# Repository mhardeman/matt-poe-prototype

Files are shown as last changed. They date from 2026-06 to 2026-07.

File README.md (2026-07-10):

# matt-poe-prototype
This is a KiCad design containing a schematic & PCB layout for a prototype PoE (Power over Ethernet) PD (Powered Device).

It provides for output isolation between the PoE delivery and the output power rails.  It provides for both 12V and 5V output rails, with a common ground for those two rails.

This is a prototype.  I'm happy to accept issues with questions or suggestions for improvement, and would very happily review any pull requests that come in.

## Update 2026/07/09
Apparently some one(s) at [PCBWay](https://pcbway.com) saw this Github project or my post(s) about it on Reddit, because a representative from PCBWay reached out to me and offered to sponsor a run of these boards for free and even let me get a free solder stencil with the boards, all for the simple ask that I provide an honest review of the sponsored boards & stencil.  My review is: they look & feel great, and they function fantastically.  I'll be posting more -- including an assembly and testing video -- in the coming days.  In the mean time, check out the [photos of the PCBWay boards](pcbway/)  All told, PCBWay let me put together a purchase of these boards, the stencil, and some premium options, and shipping, all without cost to me.  It's wonderful to see a company serving both hobbyists and industry ALSO materially contribute!  I'm grateful.

## Detailed Description

This design utilizes the 3Peak TPE15017 and/or Monolithic Power Systems MP8017 -- they're largely interchangeable in this design, though tolerances on the 3Peak seem to be favorable, which can improve your efficiency.  This tiny IC handles the PoE power detection and classification and provides an active-clamp flyback controller with integrated low-side & clamp MOSFETs.  This part, in conjunction with an appropriate transformer provides a 12V output rail, which is further routed in this design to an inexpensive buck converter to provide for a 5V output rail.

In my testing up to this point, this design easily provides at least 10W of usable power out the 5V rail.  I've had it pulling 5V/2A on my DC test load continuously for several days.

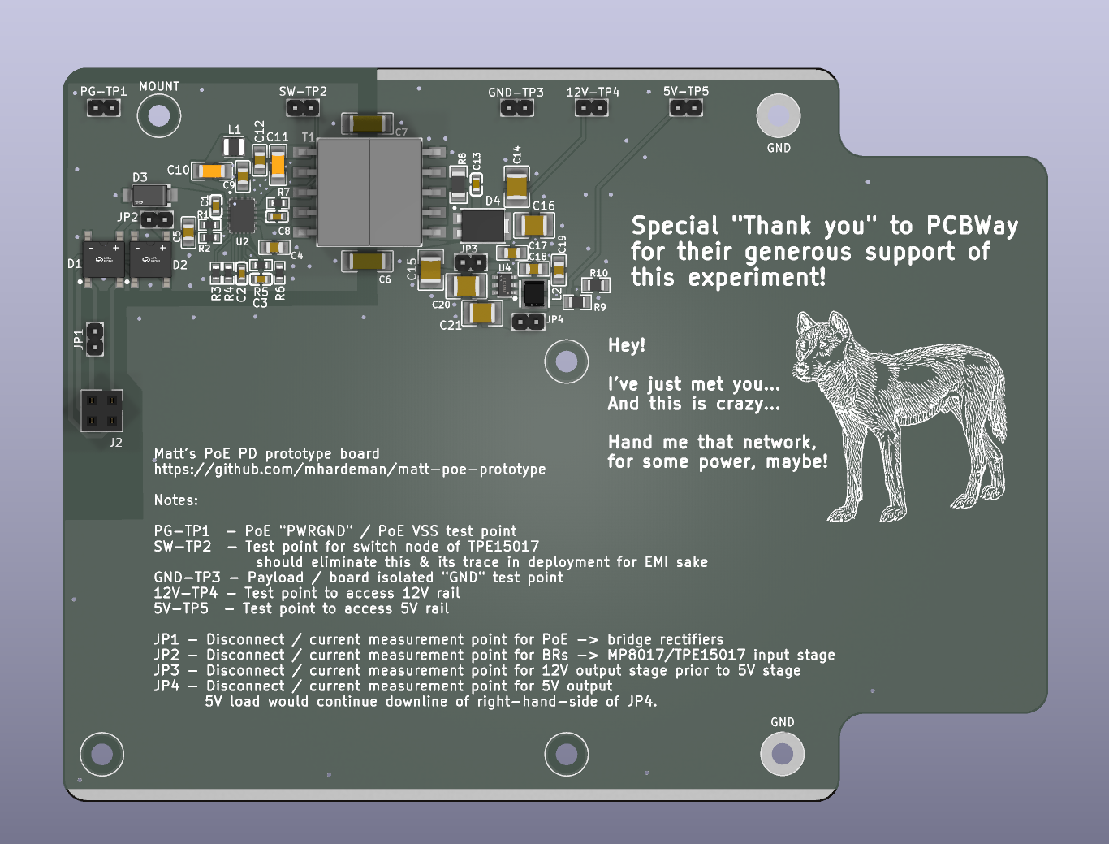
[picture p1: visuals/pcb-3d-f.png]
3D view


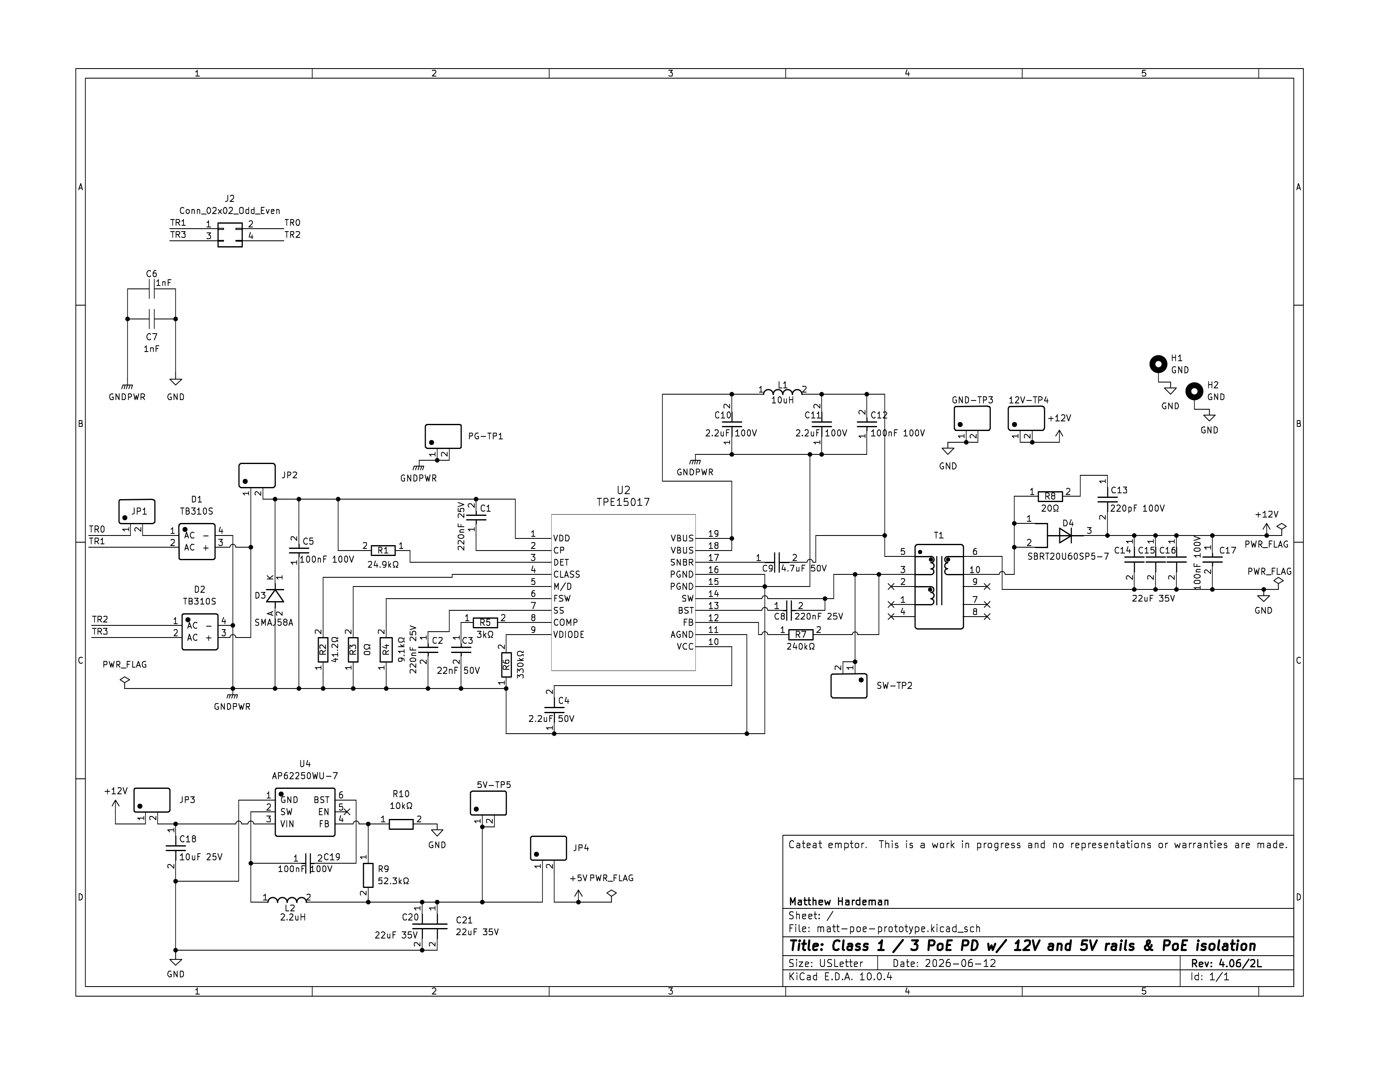
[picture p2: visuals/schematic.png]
Schematic


[Bill of Materials](matt-poe-prototype.csv)

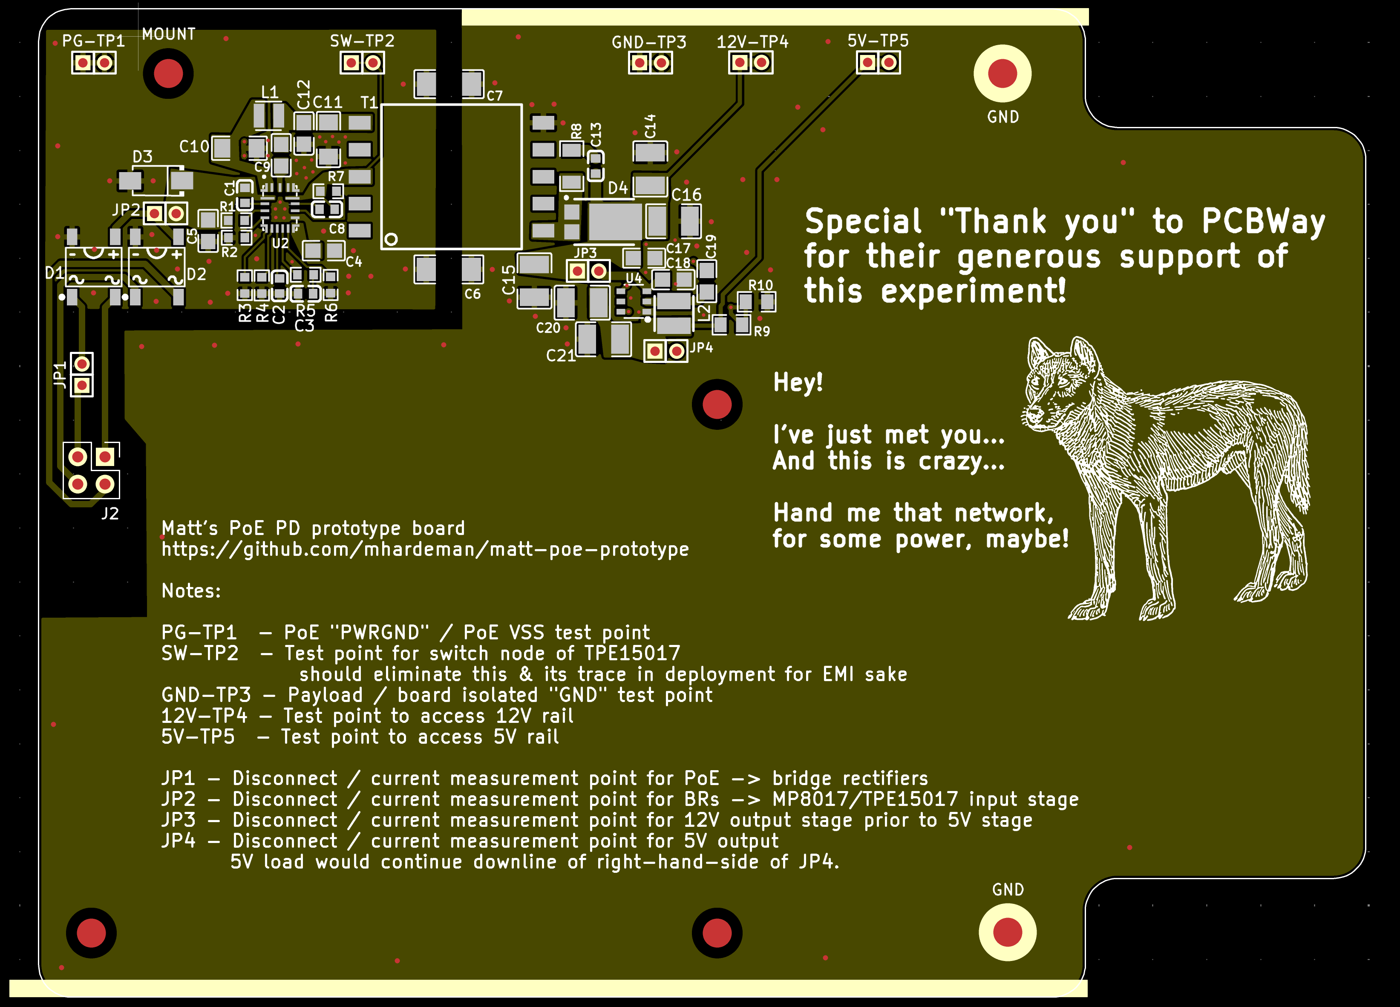
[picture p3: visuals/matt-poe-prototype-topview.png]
Top view


[More visuals](visuals/)

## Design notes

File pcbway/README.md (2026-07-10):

# PCBWay Boards & Stencil
[PCBWay](https://pcbway.com) generously sponsored a run of PCBs and even allowed me to select some premium options, such as 2 ounce copper layers.
Here are a couple of photos of the excellent PCBWay products I received free of charge and a photo of one of the boards as fully assembled by me (Matt).

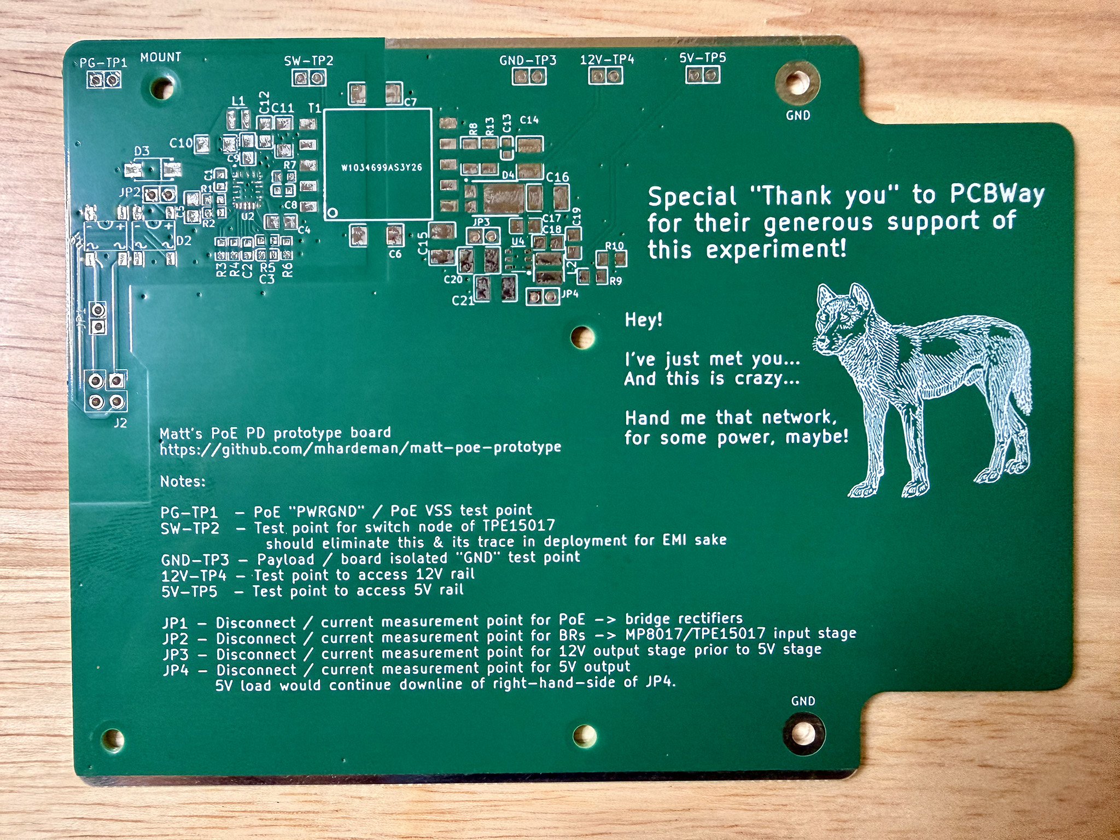
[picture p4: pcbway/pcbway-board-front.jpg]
Photo of front of PCBWay PCB


Take note of the excellent silkscreen -- I didn't put that dingo sketch on there for no reason.  All the fine detail from the design was preserved and faithfully reproduced.  The soldermask feels even more silky-smooth than it looks, while remaining durable and scratch resistant.  The simple HASL surface treatment that I selected was remarkably flat and smooth for HASL.  As you can see below, it supported paste reflow & hand soldering well.

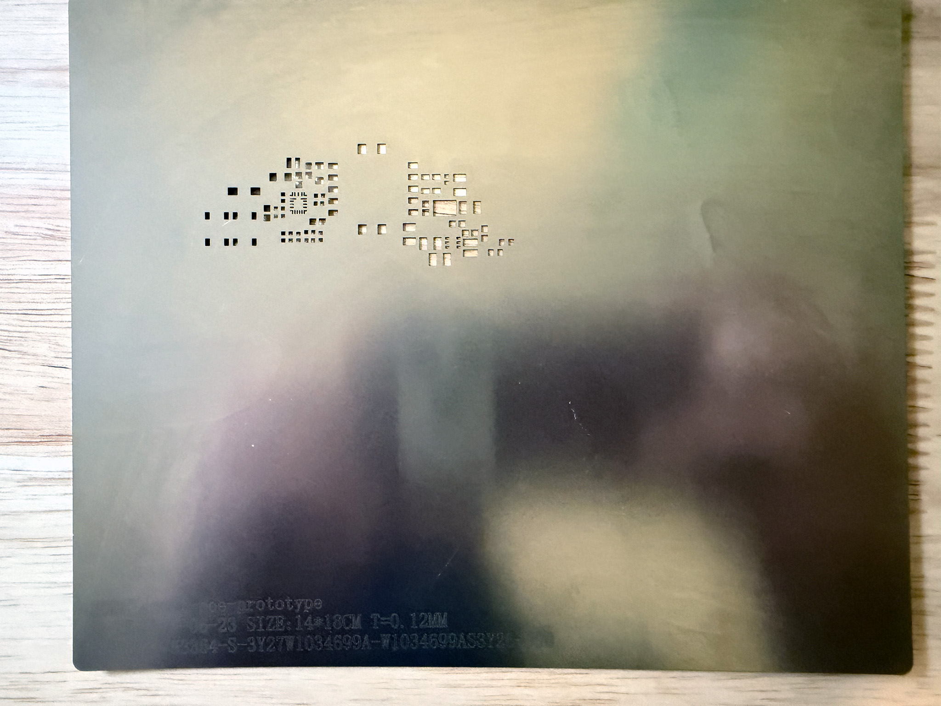
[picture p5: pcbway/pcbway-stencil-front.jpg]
Photo of PCBWay Steel Solder Paste Stencil


I asked PCBWay's representative if I could also get a solder paste stencil to show how easy populating a board with the benefit of one of their stencils can be.  I'll be posting a video of that, but for now look at the fine details and smooth, flawless opening cuts in this nicely electropolished steel stencil.  Functionally, the stencil performed very well; solder paste release was clean and even.

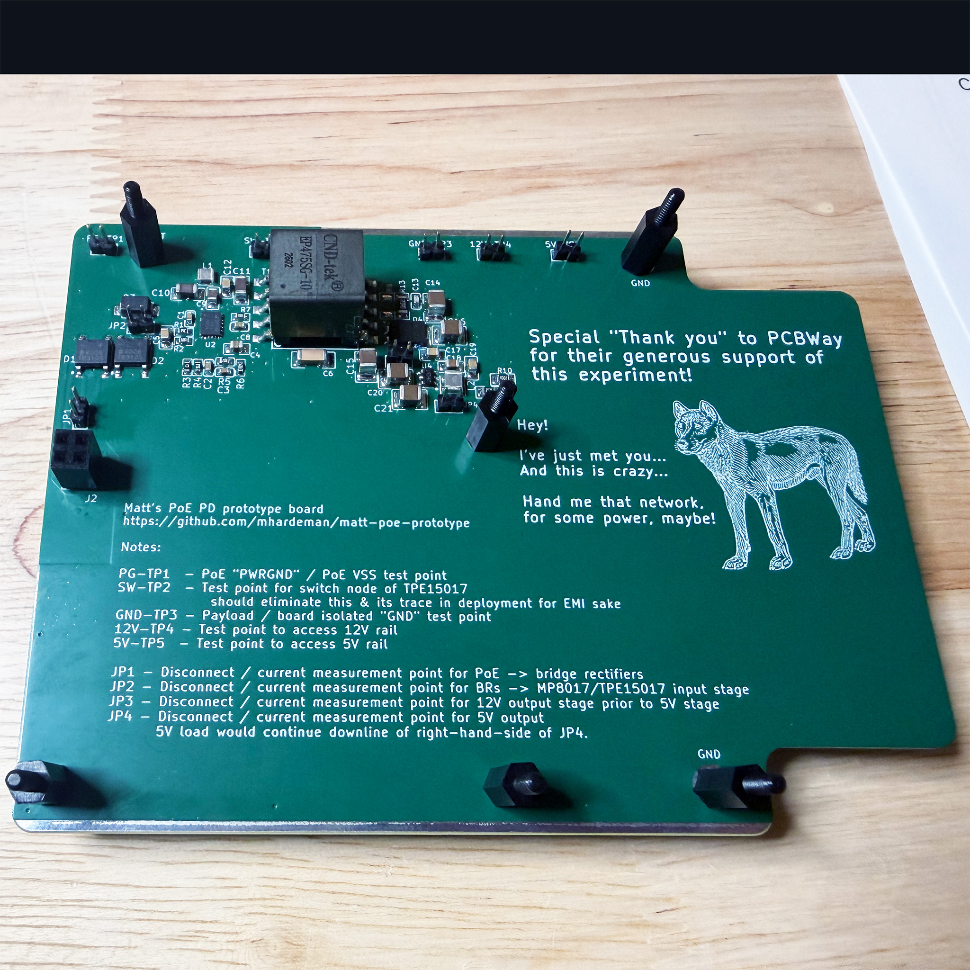
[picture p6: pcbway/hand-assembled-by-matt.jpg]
Photo of their board that I hand populated


I'll ultimately be posting a video of the assembly process, particularly demonstrating how the solder paste stencil can be such a benefit when working with fine-pitch components such as some of those in this design.  In the meantime, here's a photo of the finished board, hand populated.  I wish to emphasize that this assembly was my own work, and not from the assembly service at PCBWay.  Any flaws in the placement or soldering are my own.

# Thanks
I once again wish to express my gratitude to PCBWay for sponsoring a run of boards for this PoE powered device prototype.  The boards they provided are perfectly faithful in form, 
look great, feel premium, and function very well.  It's fantastic to see that a major vendor to both hobbyists and industry is actively seeking out opportunities to collaborate
with people who are building in public!

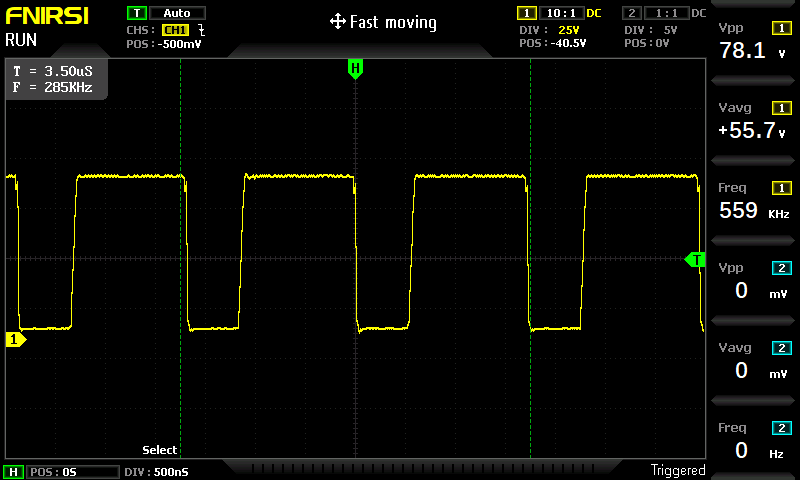
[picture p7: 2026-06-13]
visuals/switching-20260612-3.png

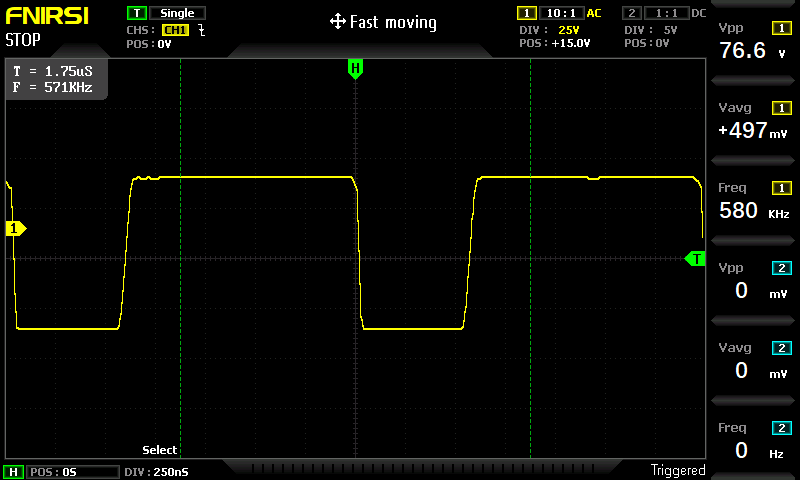
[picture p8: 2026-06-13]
visuals/switching-20260612-2.png

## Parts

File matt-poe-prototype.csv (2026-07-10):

Reference | Value | Manufacturer Part | Manufacturer | LCSC | Description
5V-TP5 | PZ200V-11-02P | PZ200V-11-02P | XFCN | C541856 | -40℃~+105℃ 1 1.5A 1x2P 2.8mm 250V 2P 2mm 2mm 3.9mm Black Brass Pin Header Through Hole 插件,P=2mm Pin Headers ROHS
12V-TP4 | PZ200V-11-02P | PZ200V-11-02P | XFCN | C541856 | -40℃~+105℃ 1 1.5A 1x2P 2.8mm 250V 2P 2mm 2mm 3.9mm Black Brass Pin Header Through Hole 插件,P=2mm Pin Headers ROHS
C1 | 220nF 25V | CL10B224KA8NNNC | Samsung Electro-Mechanics | C21120 | 220nF 25V X7R ±10% 0603 Multilayer Ceramic Capacitors MLCC - SMD/SMT ROHS
C2 | 220nF 25V | CL10B224KA8NNNC | Samsung Electro-Mechanics | C21120 | 220nF 25V X7R ±10% 0603 Multilayer Ceramic Capacitors MLCC - SMD/SMT ROHS
C3 | 22nF 50V | CL10B223KB8NNNC | Samsung Electro-Mechanics | C21122 | 22nF 50V X7R ±10% 0603 Multilayer Ceramic Capacitors MLCC - SMD/SMT ROHS
C4 | 2.2uF 50V | CL21A225KBQNNNE | Samsung Electro-Mechanics | C377773 | 2.2uF 50V X5R ±10% 0805 Multilayer Ceramic Capacitors MLCC - SMD/SMT ROHS
C5 | 100nF 100V | CL21B104KCFNNNE | Samsung Electro-Mechanics | C28233 | 100V 100nF X7R ±10% 0805 Multilayer Ceramic Capacitors MLCC - SMD/SMT ROHS
C6 | 1nF | GR442QR73D102KW01L | Murata Electronics | C76916 | 1nF 2kV X7R ±10% 1808
C7 | 1nF | GR442QR73D102KW01L | Murata Electronics | C76916 | 1nF 2kV X7R ±10% 1808
C8 | 220nF 25V | CL10B224KA8NNNC | Samsung Electro-Mechanics | C21120 | 220nF 25V X7R ±10% 0603 Multilayer Ceramic Capacitors MLCC - SMD/SMT ROHS
C9 | 4.7uF 50V | GRM21BZ71H475KE15L | Murata Electronics | C437557 | 4.7uF 50V X7R ±10% 0805 Multilayer Ceramic Capacitors MLCC - SMD/SMT ROHS
C10 | 2.2uF 100V | CL31B225KCHSNNE | Samsung Electro-Mechanics | C170101 | 100V 2.2uF X7R ±10% 1206 Multilayer Ceramic Capacitors MLCC - SMD/SMT ROHS
C11 | 2.2uF 100V | CL31B225KCHSNNE | Samsung Electro-Mechanics | C170101 | 100V 2.2uF X7R ±10% 1206 Multilayer Ceramic Capacitors MLCC - SMD/SMT ROHS
C12 | 100nF 100V | CL21B104KCFNNNE | Samsung Electro-Mechanics | C28233 | 100V 100nF X7R ±10% 0805 Multilayer Ceramic Capacitors MLCC - SMD/SMT ROHS
C13 | 220pF 100V | GCM1885C2A221JA16D | Murata Electronics | C388907 | 100V 220pF C0G ±5% 0603 Multilayer Ceramic Capacitors MLCC - SMD/SMT ROHS
C14 | 22uF 35V | GMK325BJ226MM-P | Taiyo Yuden | C778721 | 22uF 35V X5R ±20% 1210 Multilayer Ceramic Capacitors MLCC - SMD/SMT ROHS
C15 | 22uF 35V | GMK325BJ226MM-P | Taiyo Yuden | C778721 | 22uF 35V X5R ±20% 1210 Multilayer Ceramic Capacitors MLCC - SMD/SMT ROHS
C16 | 22uF 35V | GMK325BJ226MM-P | Taiyo Yuden | C778721 | 22uF 35V X5R ±20% 1210 Multilayer Ceramic Capacitors MLCC - SMD/SMT ROHS
C17 | 100nF 100V | CL21B104KCFNNNE | Samsung Electro-Mechanics | C28233 | 100V 100nF X7R ±10% 0805 Multilayer Ceramic Capacitors MLCC - SMD/SMT ROHS
C18 | 10uF 25V | GRM21BZ71E106KE15L | Murata Electronics | C237493 | 10uF 25V X7R ±10% 0805 Multilayer Ceramic Capacitors MLCC - SMD/SMT ROHS
C19 | 100nF 100V | CL21B104KCFNNNE | Samsung Electro-Mechanics | C28233 | 100V 100nF X7R ±10% 0805 Multilayer Ceramic Capacitors MLCC - SMD/SMT ROHS
C20 | 22uF 35V | GMK325BJ226MM-P | Taiyo Yuden | C778721 | 22uF 35V X5R ±20% 1210 Multilayer Ceramic Capacitors MLCC - SMD/SMT ROHS
C21 | 22uF 35V | GMK325BJ226MM-P | Taiyo Yuden | C778721 | 22uF 35V X5R ±20% 1210 Multilayer Ceramic Capacitors MLCC - SMD/SMT ROHS
D1 | TB310S | TB310S | Diotec | C382784 | -55℃~+150℃ 100V 300uA@100V 3A 70A 850mV@3A Single-Phase Rectifier ABS Bridge Rectifiers ROHS
D2 | TB310S | TB310S | Diotec | C382784 | -55℃~+150℃ 100V 300uA@100V 3A 70A 850mV@3A Single-Phase Rectifier ABS Bridge Rectifiers ROHS
D3 | SMAJ58A | SMAJ58A | hongjiacheng | C19077554 | TVS Unidirectional DO-214AC(SMA) ESD and Surge Protection (TVS/ESD) ROHS 1uA 4.3A@10/1000us 400W@10/1000us 58V 71.2V 93.6V IEC 61000-4-2 -55℃~+150℃
D4 | SBRT20U60SP5-7 | SBRT20U60SP5-7 | Diodes Incorporated | C156299 | 20A 320A 400uA 480mV@20A 60V PowerDI-5 Super Barrier Rectifiers (SBR) ROHS -55℃~+150℃
GND-TP3 | PZ200V-11-02P | PZ200V-11-02P | XFCN | C541856 | -40℃~+105℃ 1 1.5A 1x2P 2.8mm 250V 2P 2mm 2mm 3.9mm Black Brass Pin Header Through Hole 插件,P=2mm Pin Headers ROHS
J2 | Conn_02x02_Odd_Even |  |  | C2840016 | Generic connector, double row, 02x02, odd/even pin numbering scheme (row 1 odd numbers, row 2 even numbers), script generated (kicad-library-utils/schlib/autogen/connector/)
JP1 | PZ200V-11-02P | PZ200V-11-02P | XFCN | C541856 | -40℃~+105℃ 1 1.5A 1x2P 2.8mm 250V 2P 2mm 2mm 3.9mm Black Brass Pin Header Through Hole 插件,P=2mm Pin Headers ROHS
JP2 | PZ200V-11-02P | PZ200V-11-02P | XFCN | C541856 | -40℃~+105℃ 1 1.5A 1x2P 2.8mm 250V 2P 2mm 2mm 3.9mm Black Brass Pin Header Through Hole 插件,P=2mm Pin Headers ROHS
JP3 | PZ200V-11-02P | PZ200V-11-02P | XFCN | C541856 | -40℃~+105℃ 1 1.5A 1x2P 2.8mm 250V 2P 2mm 2mm 3.9mm Black Brass Pin Header Through Hole 插件,P=2mm Pin Headers ROHS
JP4 | PZ200V-11-02P | PZ200V-11-02P | XFCN | C541856 | -40℃~+105℃ 1 1.5A 1x2P 2.8mm 250V 2P 2mm 2mm 3.9mm Black Brass Pin Header Through Hole 插件,P=2mm Pin Headers ROHS
L1 | 10uH | DFE252012F-100M=P2 | Murata Electronics | C703141 | 1.4A 10uH 400mΩ 950mA ±20% 1008 Power Inductors ROHS
L2 | 2.2uH | FTC322510S2R2MBCA | cjiang (Changjiang Microelectronics Tech) | C18724399 | 2.2uH 3.7A 4A 66mΩ ±20% 1210 Power Inductors ROHS
PG-TP1 | PZ200V-11-02P | PZ200V-11-02P | XFCN | C541856 | -40℃~+105℃ 1 1.5A 1x2P 2.8mm 250V 2P 2mm 2mm 3.9mm Black Brass Pin Header Through Hole 插件,P=2mm Pin Headers ROHS
R1 | 24.9kΩ | 0603WAF2492T5E | UNI-ROYAL(Uniroyal Elec) | C25962 | -55℃~+155℃ 100mW 24.9kΩ 75V Thick Film Resistor ±1% ±100ppm/℃ 0603 Chip Resistor - Surface Mount ROHS
R2 | 41.2Ω | 0603WAF412JT5E | UNI-ROYAL(Uniroyal Elec) | C246850 | -55℃~+155℃ 100mW 41.2Ω 75V Thick Film Resistor ±1% ±100ppm/℃ 0603 Chip Resistor - Surface Mount ROHS
R3 | 0Ω | 0603WAF0000T5E | UNI-ROYAL(Uniroyal Elec) | C21189 | -55℃~+155℃ 0Ω 100mW 75V Thick Film Resistor ±1% 0603 Chip Resistor - Surface Mount ROHS
R4 | 9.1kΩ | FRC0603J912 TS | FOJAN | C2907210 | -55℃~+155℃ 100mW 75V 9.1kΩ Thick Film Resistor ±100ppm/℃ ±5% 0603 Chip Resistor - Surface Mount ROHS
R5 | 3kΩ | 0603WAF3001T5E | UNI-ROYAL(Uniroyal Elec) | C4211 | -55℃~+155℃ 100mW 3kΩ 75V Thick Film Resistor ±1% ±100ppm/℃ 0603 Chip Resistor - Surface Mount ROHS
R6 | 330kΩ | 0603WAF3303T5E | UNI-ROYAL(Uniroyal Elec) | C23137 | -55℃~+155℃ 100mW 330kΩ 75V Thick Film Resistor ±1% ±100ppm/℃ 0603 Chip Resistor - Surface Mount ROHS
R7 | 240kΩ | 0603WAF2403T5E | UNI-ROYAL(Uniroyal Elec) | C4197 | -55℃~+155℃ 100mW 240kΩ 75V Thick Film Resistor ±1% ±100ppm/℃ 0603 Chip Resistor - Surface Mount ROHS
R8 | 20Ω | RC1206FR-7W20RL | Yageo | C859156 | 20Ω 500mW
R9 | 52.3kΩ | 0805W8F5232T5E | UNI-ROYAL(Uniroyal Elec) | C17740 | -55℃~+155℃ 125mW 150V 52.3kΩ Thick Film Resistor ±1% ±100ppm/℃ 0805 Chip Resistor - Surface Mount ROHS
R10 | 10kΩ | 0805W8F1002T5E | UNI-ROYAL(Uniroyal Elec) | C17414 | -55℃~+155℃ 10kΩ 125mW 150V Thick Film Resistor ±1% ±100ppm/℃ 0805 Chip Resistor - Surface Mount ROHS
SW-TP2 | PZ200V-11-02P | PZ200V-11-02P | XFCN | C541856 | -40℃~+105℃ 1 1.5A 1x2P 2.8mm 250V 2P 2mm 2mm 3.9mm Black Brass Pin Header Through Hole 插件,P=2mm Pin Headers ROHS
T1 | EP475SG-10 | EP475SG-10 | CND-tek | C42401037 | 12V 1:0.5:0.55 2.1A 37uH 37~57V 750nH SMD-10P,13.5x13mm Power Transformers ROHS
U2 | TPE15017 |  | 3Peak | C26159122 | Integrated PoE Frontend & DC/DC controller with FETs
U4 | AP62250WU-7 | AP62250WU-7 | Diodes Incorporated | C5184228 | -40℃~+85℃ 1 1.3MHz 155uA 2.5A 4.2V~18V 800mV~7V Adjustable Buck Buck Built-in Yes TSOT-26 DC-DC Converters ROHS

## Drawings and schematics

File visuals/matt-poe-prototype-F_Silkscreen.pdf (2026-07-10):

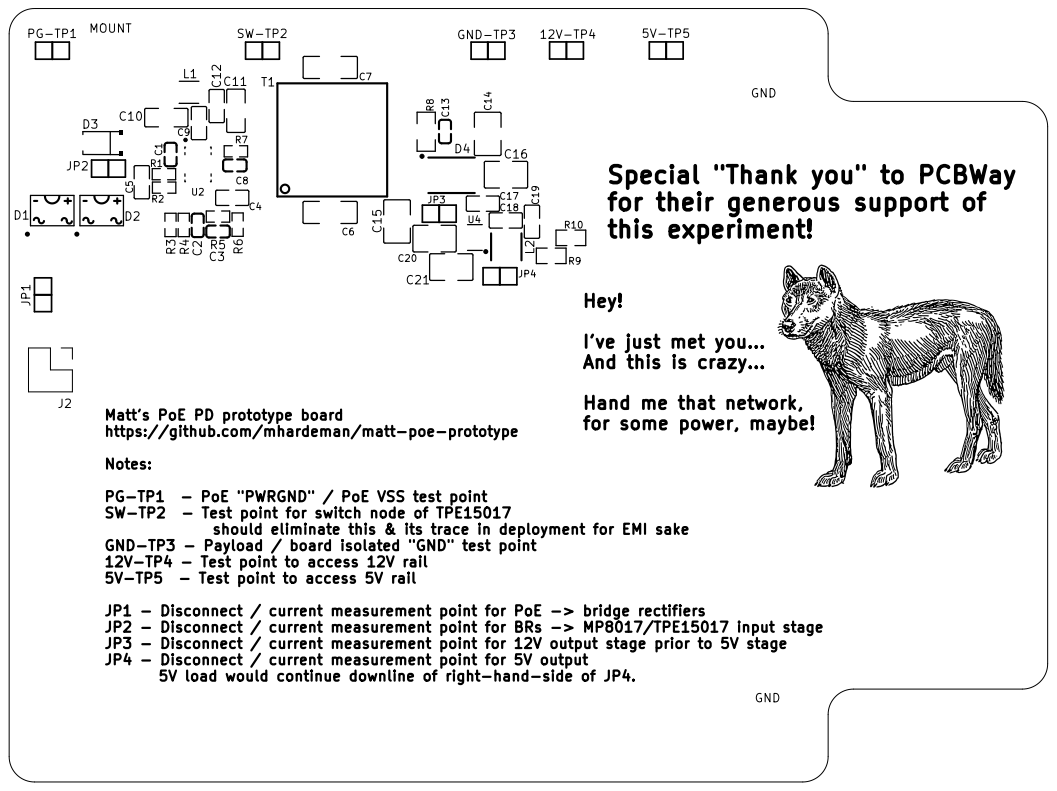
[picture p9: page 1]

Special "Thank you" to PCBWay
for their generous support of

JP4 - Disconnect / current measurement point for 5V output 5V load would continue downline of right-hand-side of JP4. Hey!

I've just met you...
And this is crazy...

Matt's PoE PD prototype board
https://github.com/mhardeman/matt-poe-prototype Notes: PG-TP1 - PoE "PWRGND" / PoE VSS test point SW-TP2 - Test point for switch node of TPE15017

Hand me that network,
for some power, maybe!

should eliminate this & its trace in deployment for EMI sake GND-TP3 - Payload / board isolated "GND" test point 12V-TP4 - Test point to access 12V rail 5V-TP5 - Test point to access 5V rail JP1 - Disconnect / current measurement point for PoE -> bridge rectifiers

JP2 - Disconnect / current measurement point for BRs -> MP8017/TPE15017 input stage
JP3 - Disconnect / current measurement point for 12V output stage prior to 5V stage

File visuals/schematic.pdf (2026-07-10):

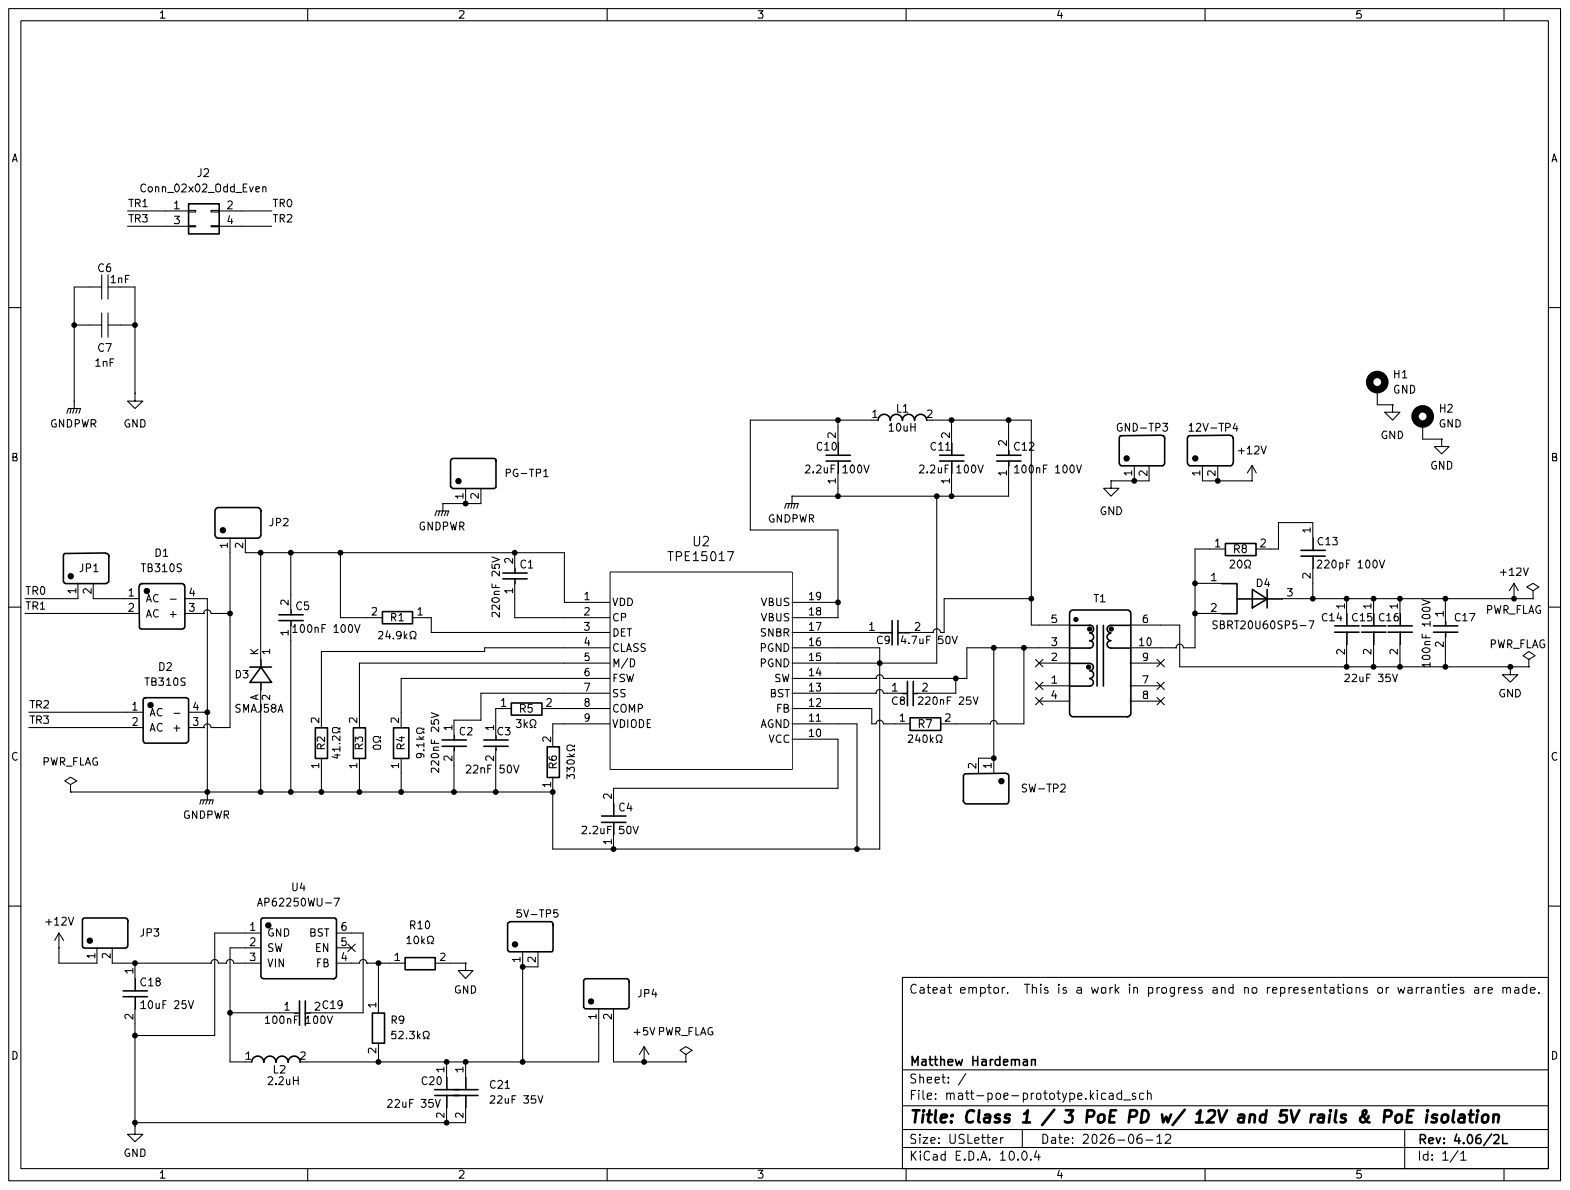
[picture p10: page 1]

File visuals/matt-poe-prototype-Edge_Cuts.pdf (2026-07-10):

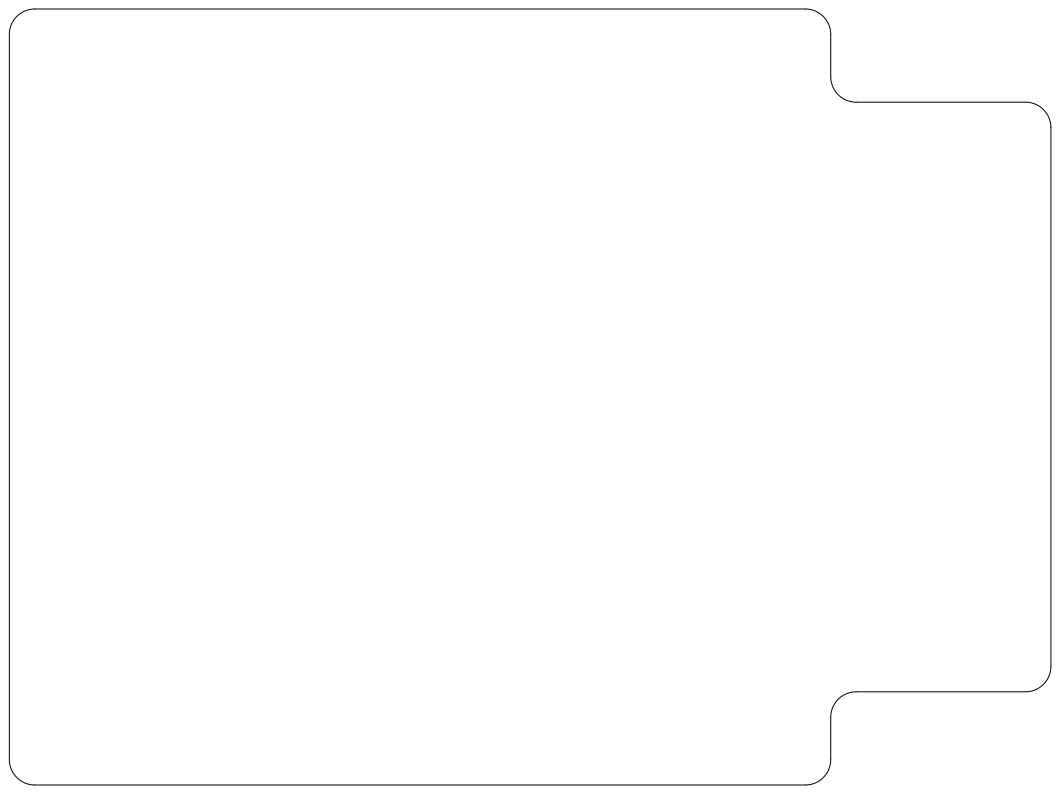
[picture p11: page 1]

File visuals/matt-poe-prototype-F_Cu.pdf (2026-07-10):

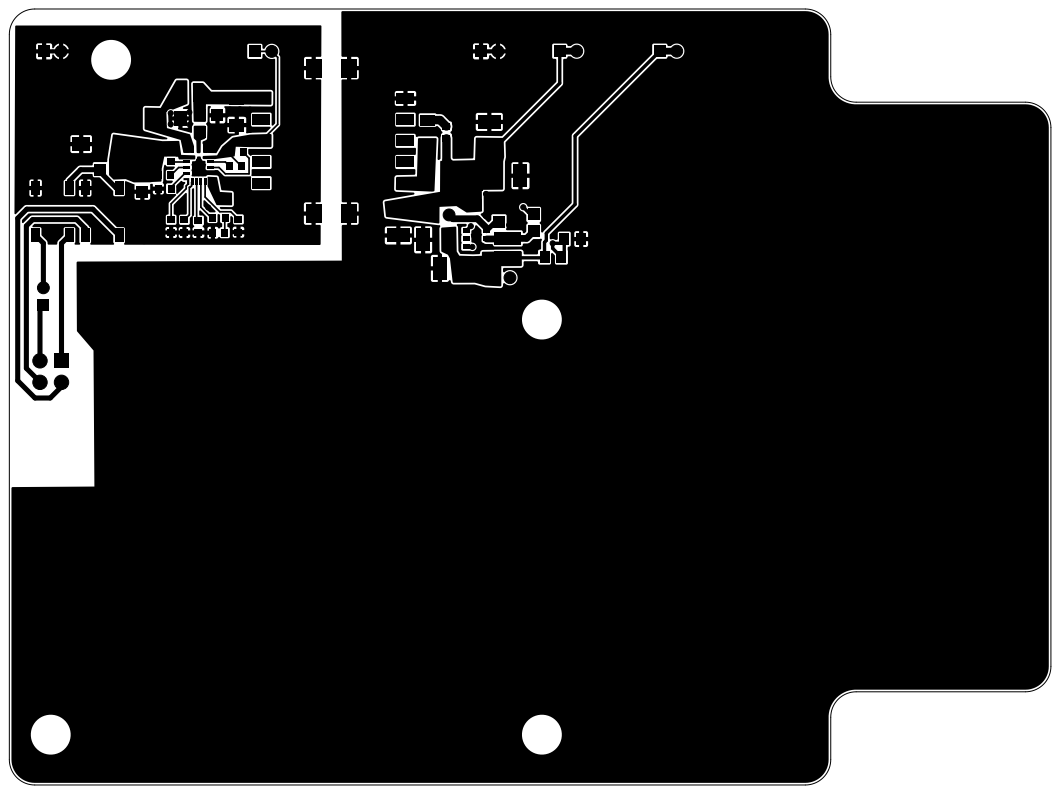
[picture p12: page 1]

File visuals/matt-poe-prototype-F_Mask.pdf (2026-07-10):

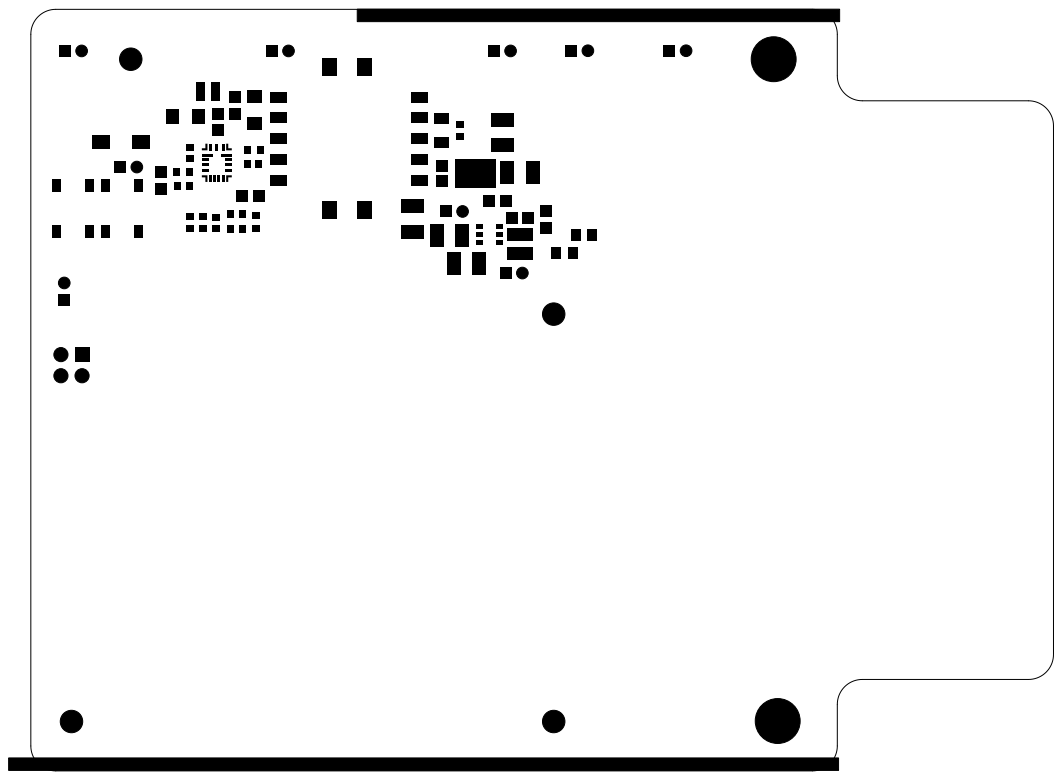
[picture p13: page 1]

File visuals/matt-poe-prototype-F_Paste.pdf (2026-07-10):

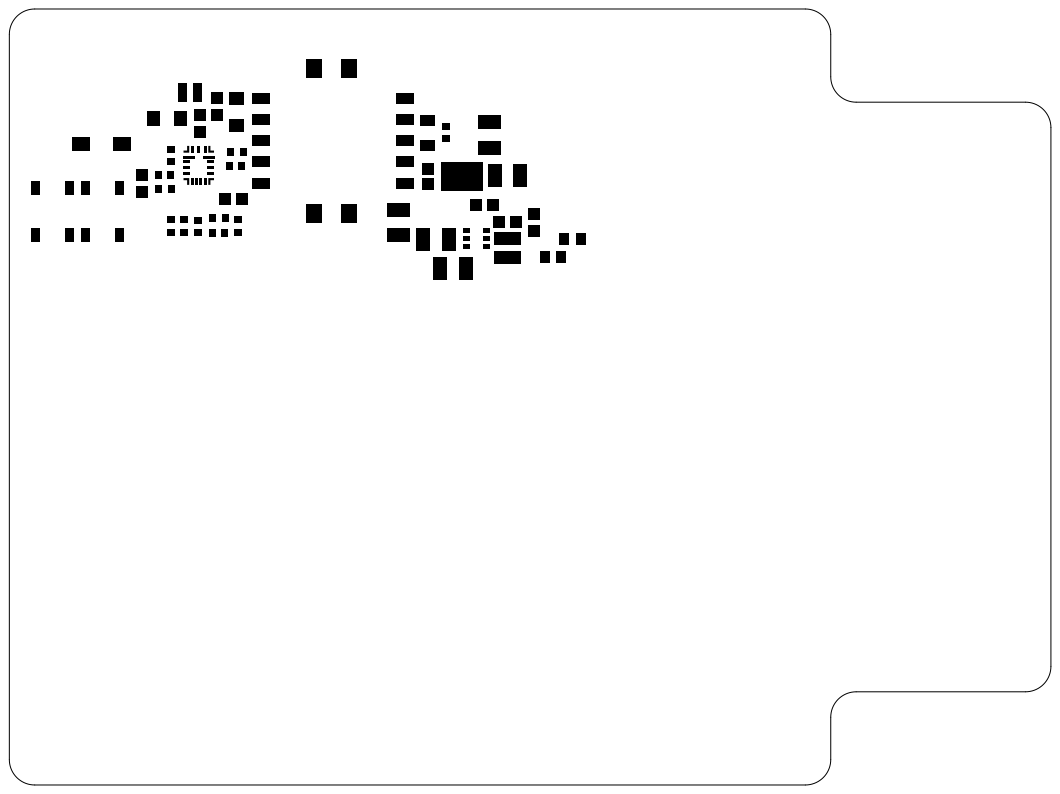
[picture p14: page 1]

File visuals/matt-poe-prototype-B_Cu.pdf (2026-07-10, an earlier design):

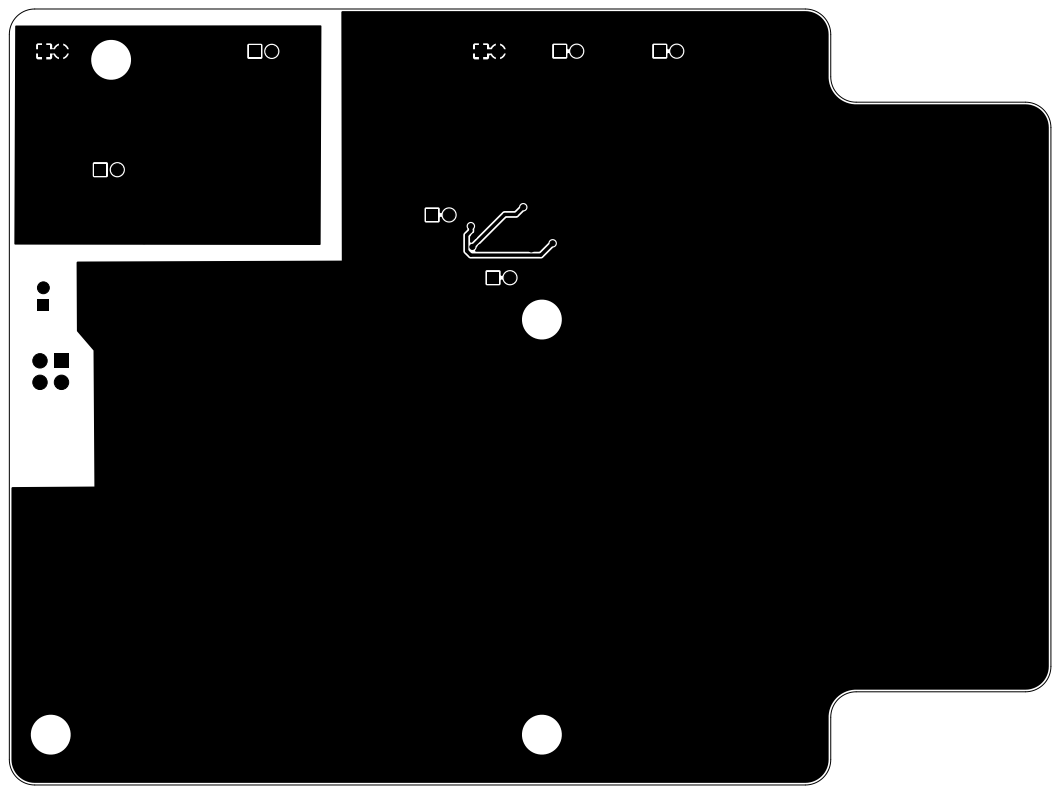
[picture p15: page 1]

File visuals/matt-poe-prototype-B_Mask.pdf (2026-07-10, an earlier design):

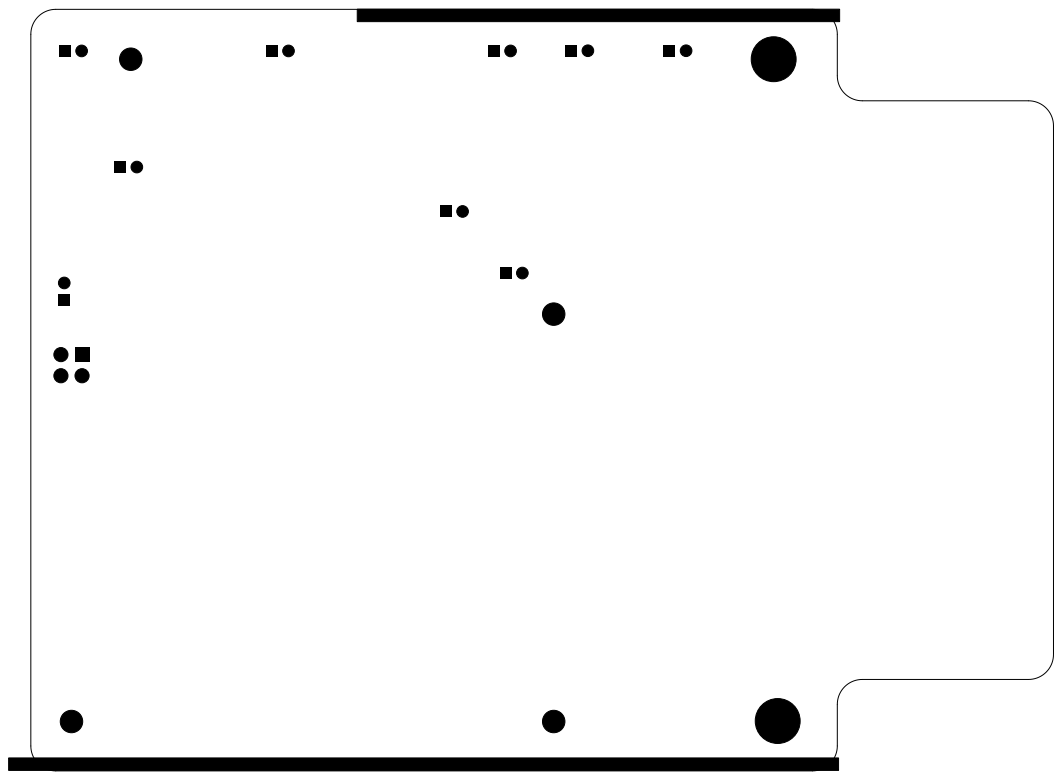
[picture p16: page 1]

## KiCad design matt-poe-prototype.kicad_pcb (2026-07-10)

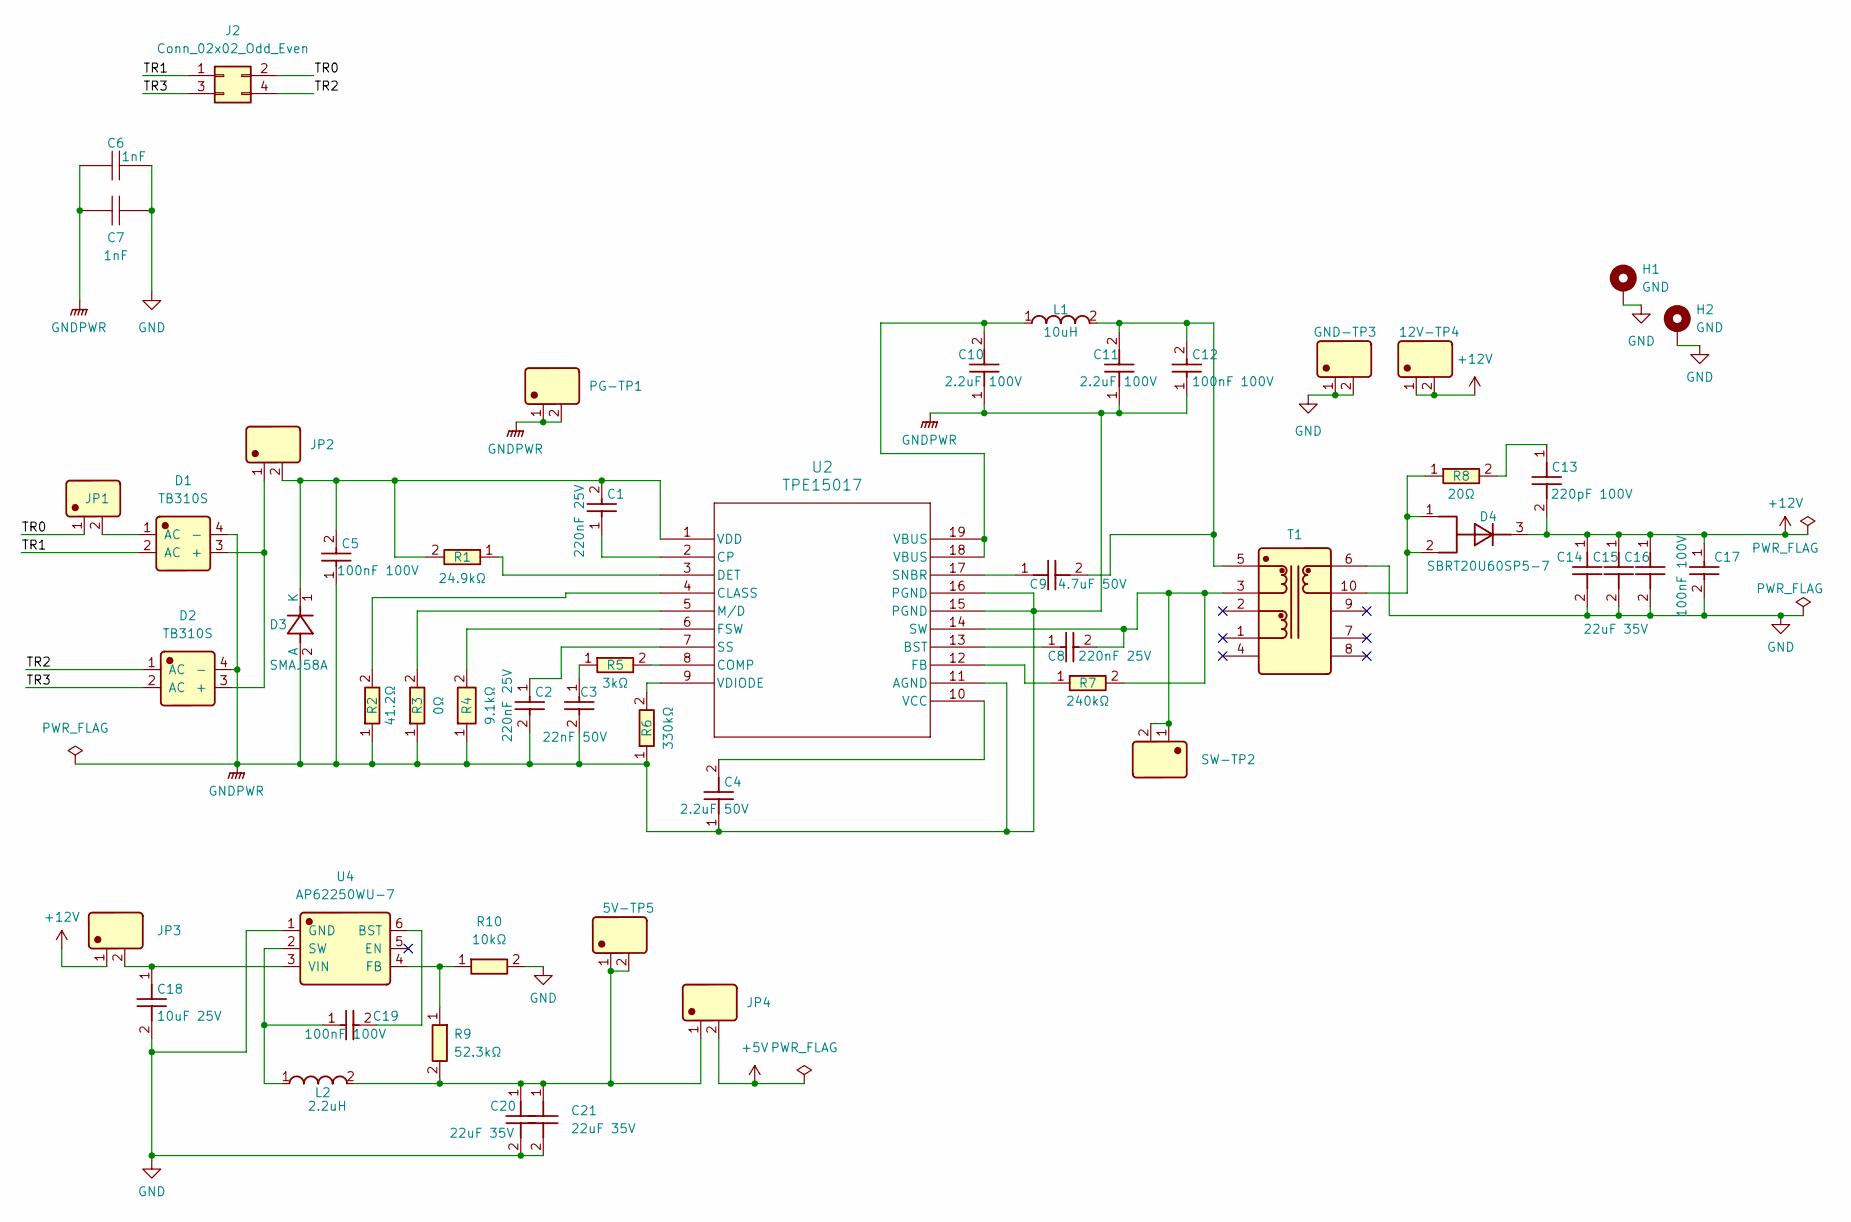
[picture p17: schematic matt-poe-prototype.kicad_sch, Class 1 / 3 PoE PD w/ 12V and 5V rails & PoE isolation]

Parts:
5V-TP5, 12V-TP4: PZ200V-11-02P; Manufacturer Part PZ200V-11-02P; LCSC C541856
C1, C2, C8: 220nF 25V; CL10B224KA8NNNC; Manufacturer Part CL10B224KA8NNNC; LCSC C21120
C3: 22nF 50V; C_0603_C21122; Manufacturer Part CL10B223KB8NNNC; LCSC C21122
C4: 2.2uF 50V; C_0805_C377773; Manufacturer Part CL21A225KBQNNNE; LCSC C377773
C5, C12, C17, C19: 100nF 100V; C_0805_C28233; Manufacturer Part CL21B104KCFNNNE; LCSC C28233
C6, C7: 1nF; C1808; MPN GR442QR73D102KW01L; LCSC C76916
C9: 4.7uF 50V; C_0805_C437557; Manufacturer Part GRM21BZ71H475KE15L; LCSC C437557
C10, C11: 2.2uF 100V; C_1206_C170101; Manufacturer Part CL31B225KCHSNNE; LCSC C170101
C13: 220pF 100V; GCM1885C2A221JA16D; Manufacturer Part GCM1885C2A221JA16D; LCSC C388907
C14, C15, C16, C20, C21: 22uF 35V; C_1210_C778721; Manufacturer Part GMK325BJ226MM-P; LCSC C778721
C18: 10uF 25V; GRM21BZ71E106KE15L; Manufacturer Part GRM21BZ71E106KE15L; LCSC C237493
D1, D2: TB310S; ABS_TB310S; Manufacturer Part TB310S; LCSC C382784
D3: SMAJ58A; SMAJ58A_C19077554; Manufacturer Part SMAJ58A; LCSC C19077554
D4: SBRT20U60SP5-7; Manufacturer Part SBRT20U60SP5-7; LCSC C156299
GND-TP3: PZ200V-11-02P; Manufacturer Part PZ200V-11-02P; LCSC C541856
H1, H2: GND; MountingHole_2.7mm_M2.5_Pad_TopBottom
J2: Conn_02x02_Odd_Even; PinSocket_2x02_P2.54mm_Vertical; MPN 61300421821; LCSC C2840016
JP1, JP2, JP3, JP4: PZ200V-11-02P; Manufacturer Part PZ200V-11-02P; LCSC C541856
L1: 10uH; DFE252012F-100M_P2; Manufacturer Part DFE252012F-100M=P2; LCSC C703141
L2: 2.2uH; L_1210_C18724399; Manufacturer Part FTC322510S2R2MBCA; LCSC C18724399
PG-TP1: PZ200V-11-02P; Manufacturer Part PZ200V-11-02P; LCSC C541856
R1: 24.9kΩ; R_0603_C25962; Manufacturer Part 0603WAF2492T5E; LCSC C25962
R2: 41.2Ω; R_0603_C246850; Manufacturer Part 0603WAF412JT5E; LCSC C246850
R3: 0Ω; R_0603_C21189; Manufacturer Part 0603WAF0000T5E; LCSC C21189
R4: 9.1kΩ; FRC0603J912_TS; Manufacturer Part FRC0603J912 TS; LCSC C2907210
R5: 3kΩ; R_0603_C4211; Manufacturer Part 0603WAF3001T5E; LCSC C4211
R6: 330kΩ; 0603WAF3303T5E; Manufacturer Part 0603WAF3303T5E; LCSC C23137
R7: 240kΩ; R_0603_C4197; Manufacturer Part 0603WAF2403T5E; LCSC C4197
R8: 20Ω; R_1206_C17903; Manufacturer Part RC1206FR-7W20RL; LCSC C859156
R9: 52.3kΩ; R_0805_C17740; Manufacturer Part 0805W8F5232T5E; LCSC C17740
R10: 10kΩ; R_0805_C17414; Manufacturer Part 0805W8F1002T5E; LCSC C17414
SW-TP2: PZ200V-11-02P; Manufacturer Part PZ200V-11-02P; LCSC C541856
T1: EP475SG-10; XFMR_EP13_EP475SG-10; Manufacturer Part EP475SG-10; LCSC C42401037
U2: TPE15017; QFN-19_MP8017_MNP; MPN TPE15017; LCSC C26159122
U4: AP62250WU-7; Manufacturer Part AP62250WU-7; LCSC C5184228

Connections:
+5V: JP4.2
+12V: 12V-TP4.1, 12V-TP4.2, C13.2, C14.1, C15.1, C16.1, C17.1, D4.3, JP3.1
/TR0: J2.2, JP1.1
/TR1: D1.2 (AC), J2.1
/TR2: D2.1 (AC), J2.4
/TR3: D2.2 (AC), J2.3
GND: C6.2, C7.2, C14.2, C15.2, C16.2, C17.2, C18.2, C20.2, C21.2, GND-TP3.1, GND-TP3.2, H1.1 (1_1), H2.1 (1_1), R10.2, T1.6, U4.1 (GND)
GNDPWR: C2.2, C3.2, C4.1, C5.1, C6.1, C7.1, C10.1, C11.1, C12.1, D1.4 (-), D2.4 (-), D3.2 (A), PG-TP1.1, PG-TP1.2, R2.1, R3.1, R4.1, R6.1, U2.11 (AGND), U2.15 (PGND), U2.16 (PGND)
unnamed: 5V-TP5.1, 5V-TP5.2, C20.1, C21.1, JP4.1, L2.2, R9.2
unnamed: C3.1, R5.1
unnamed: C10.2, L1.1, U2.18 (VBUS), U2.19 (VBUS)
unnamed: C9.2, C11.2, C12.2, L1.2, T1.5
unnamed: C13.1, R8.2
unnamed: D1.3 (+), D2.3 (+), JP2.1
unnamed: D1.1 (AC), JP1.2
unnamed: C1.2, C5.2, D3.1 (K), JP2.2, R1.2, U2.1 (VDD)
unnamed: D4.1, D4.2, R8.1, T1.10
unnamed: C8.1, U2.13 (BST)
unnamed: R2.2, U2.4 (CLASS)
unnamed: R5.2, U2.8 (COMP)
unnamed: C1.1, U2.2 (CP)
unnamed: R1.1, U2.3 (DET)
unnamed: R7.1, U2.12 (FB)
unnamed: R4.2, U2.6 (FSW)
unnamed: R3.2, U2.5 (M/D)
unnamed: C9.1, U2.17 (SNBR)
unnamed: C2.1, U2.7 (SS)
unnamed: C8.2, R7.2, SW-TP2.1, SW-TP2.2, T1.3, U2.14 (SW)
unnamed: C4.2, U2.10 (VCC)
unnamed: R6.2, U2.9 (VDIODE)
unnamed: C19.2, U4.6 (BST)
unnamed: R9.1, R10.1, U4.4 (FB)
unnamed: C19.1, L2.1, U4.2 (SW)
unnamed: C18.1, JP3.2, U4.3 (VIN)

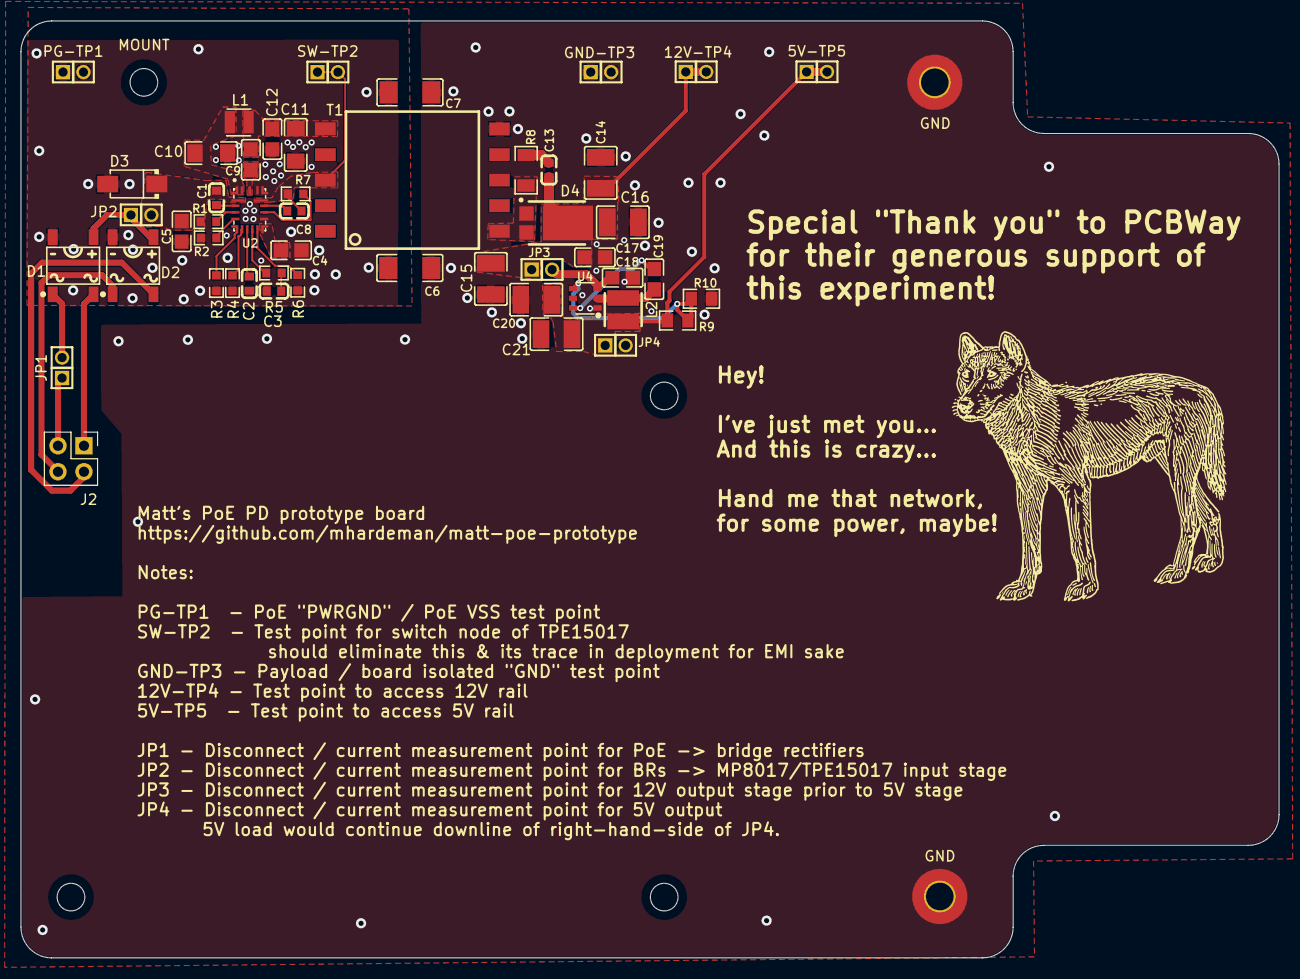
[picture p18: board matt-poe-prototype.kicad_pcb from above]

Board: 2 copper layers, 123.0 x 91.6 mm, 56 parts (0 on the bottom side), 33 nets.

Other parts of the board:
MH2, MH3, MH4: MountingHole_2.7mm_M2.5
MOUNT: MountingHole_2.7mm_M2.5

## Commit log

2026-06-12 I would like BOM to be uploadable
2026-06-12 Initial project submission
    [matt-poe-prototype-B_Cu.gbl, matt-poe-prototype-B_Fab.gbr, matt-poe-prototype-B_Mask.gbs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]
2026-06-12 added schematic png file
2026-06-12 Update README.md
    Added schematic png to readme
2026-06-12 Adding visualization of front board design
2026-06-13 adding some real life switch node waveforms when running under mild load
2026-07-10 Some component substitutions for optimization and for part availability.
    [matt-poe-prototype-B_Cu.gbl, matt-poe-prototype-B_Fab.gbr, matt-poe-prototype-B_Mask.gbs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]
2026-07-10 Updated visuals / ancilary files to reflect recent project modifications
    [matt-poe-prototype-B_Cu.gbl, matt-poe-prototype-B_Fab.gbr, matt-poe-prototype-B_Mask.gbs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]
2026-07-10 Adding further visuals, photos, etc.
    [matt-poe-prototype.kicad_pcb]
2026-07-10 Update README.md
    Updating the main readme to include a note about the PCBWay sponsored products and to add links to the photos and note about future assembly & testing video.
2026-07-10 Update README.md
    Added a README.md to the pcbway photos folder to give a tour of the photos and add some descriptions.
2026-07-10 Update README.md
    Mentioned materials and services included in the sponsorship
2026-07-10 Updating BOM and BOM formatting
    [matt-poe-prototype.csv, matt-poe-prototype.kicad_sch]
